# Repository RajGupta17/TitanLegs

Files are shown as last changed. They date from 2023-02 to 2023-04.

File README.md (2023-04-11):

## Description

TitanLegs is a 4 legged Quadruped robot which requires BLDC motors to actuate. And this is a 4 layered BLDC Servo Controller PCB which can operate upto 60V; 100A. This board has in-built micro-controller (ESP32), Gate Driver (DRV8323RS) that drives the BLDC Motor, High Voltage MOSFETs, Encoders (AS5047P), CAN BUS IC, 60V to 3.3V (2.5A) Buck Converter (TPS54260), USB to UART (CP2102) communication for programming ESP32 with Type-C, and few internal circuitry.

## 3D Model:

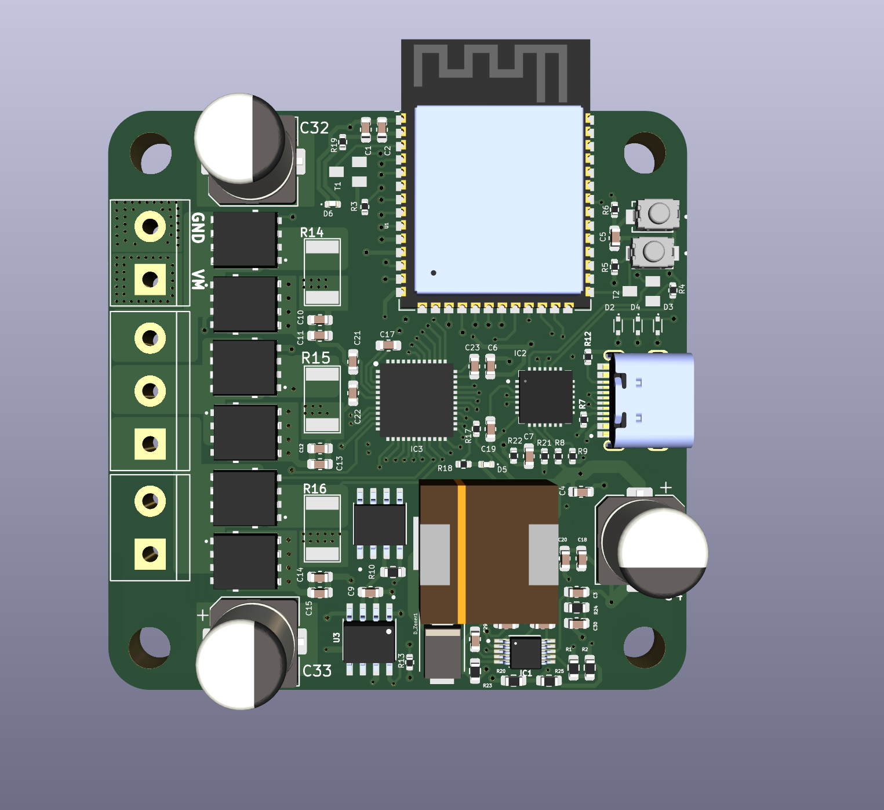
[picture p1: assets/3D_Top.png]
3D_Top


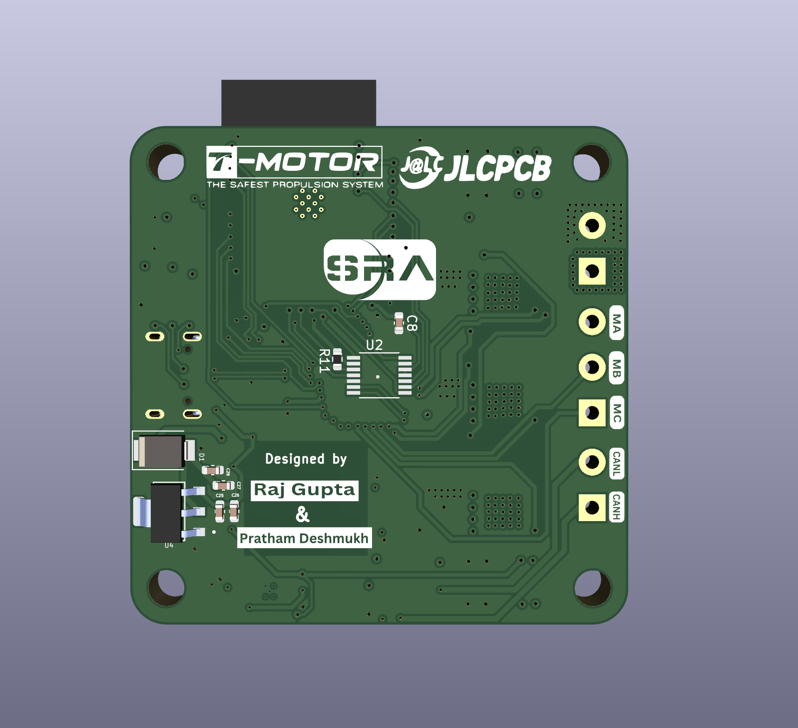
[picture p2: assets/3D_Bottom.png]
3D_Bottom


## Schematic Design:

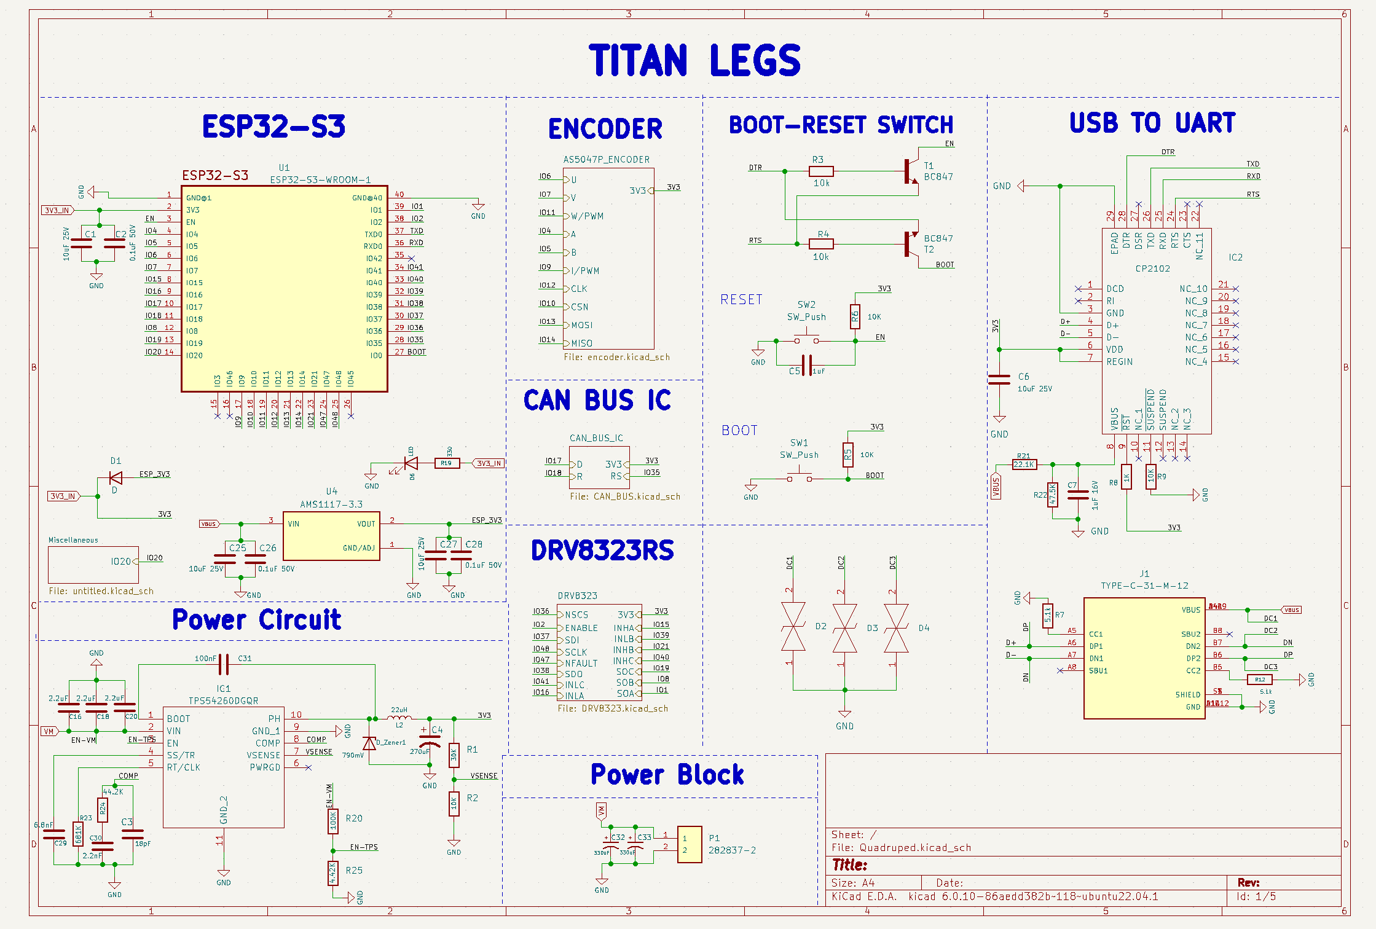
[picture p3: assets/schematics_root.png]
schematics_1


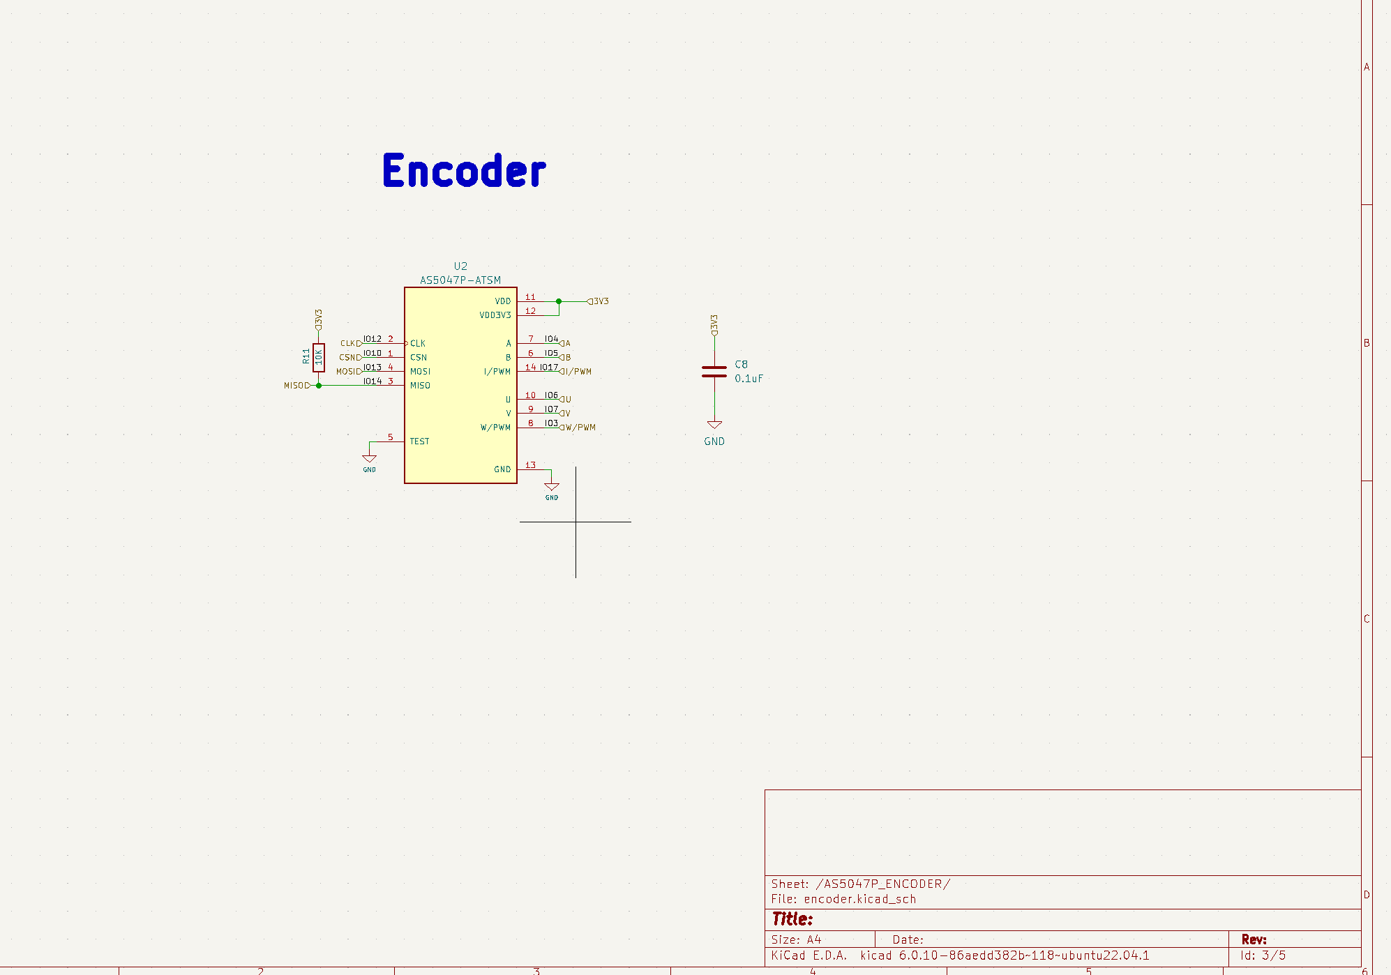
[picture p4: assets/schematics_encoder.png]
schematics encoder


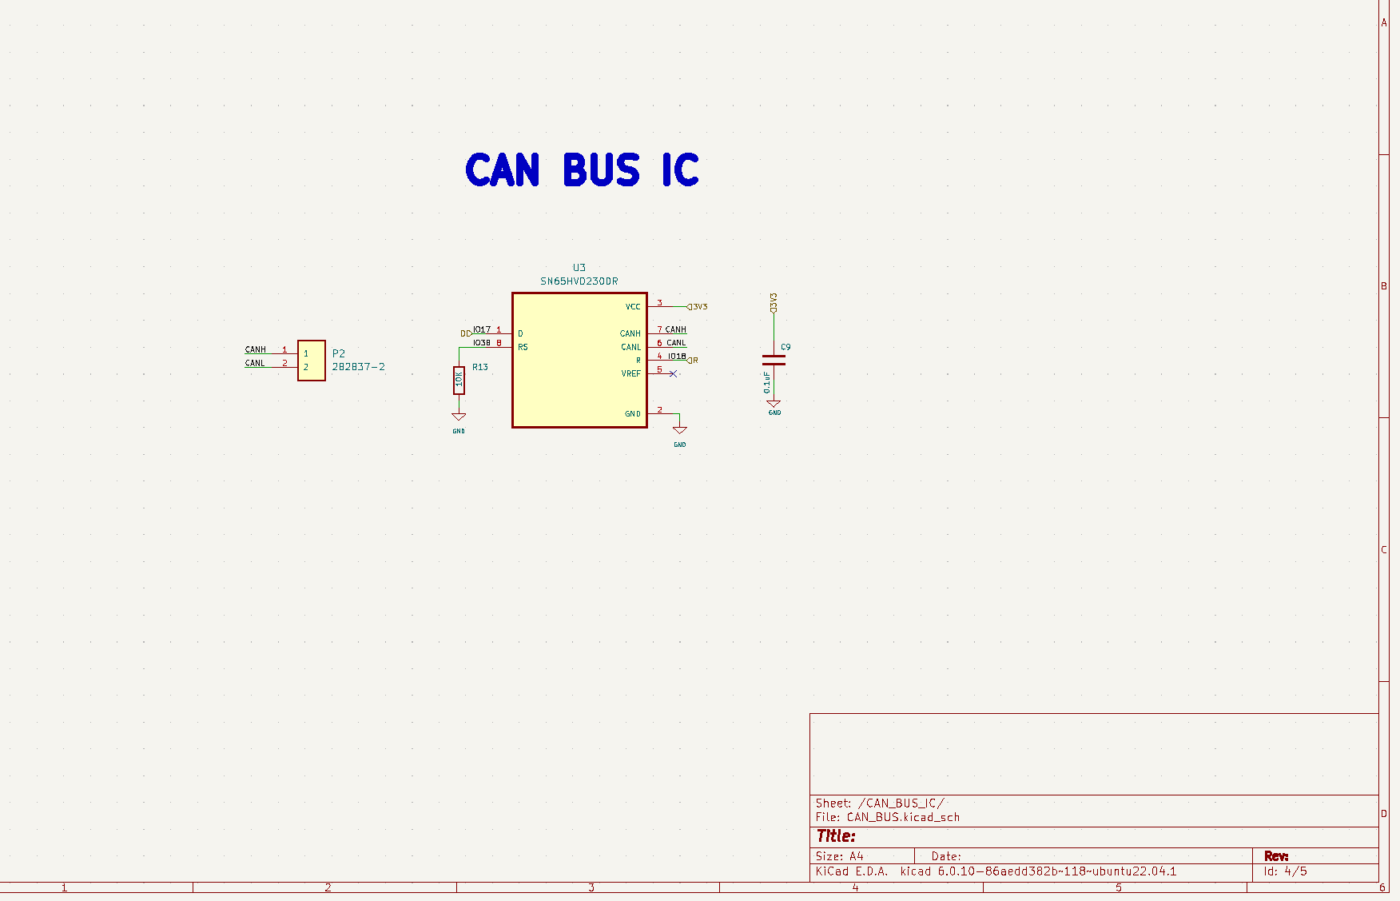
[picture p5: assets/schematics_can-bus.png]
schematics can bus


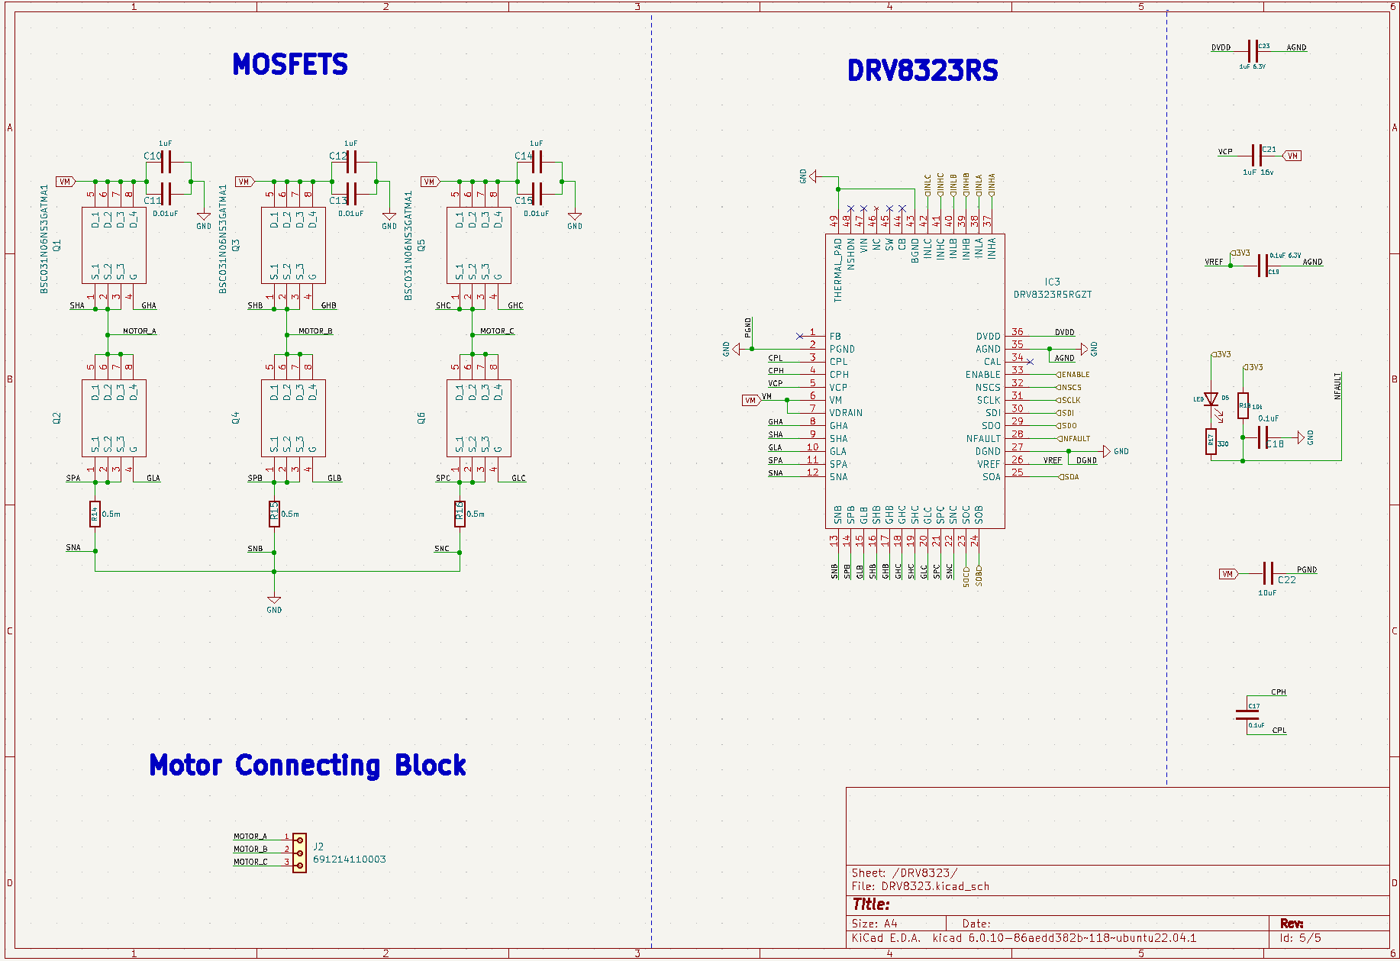
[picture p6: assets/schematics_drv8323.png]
schematics drv8323


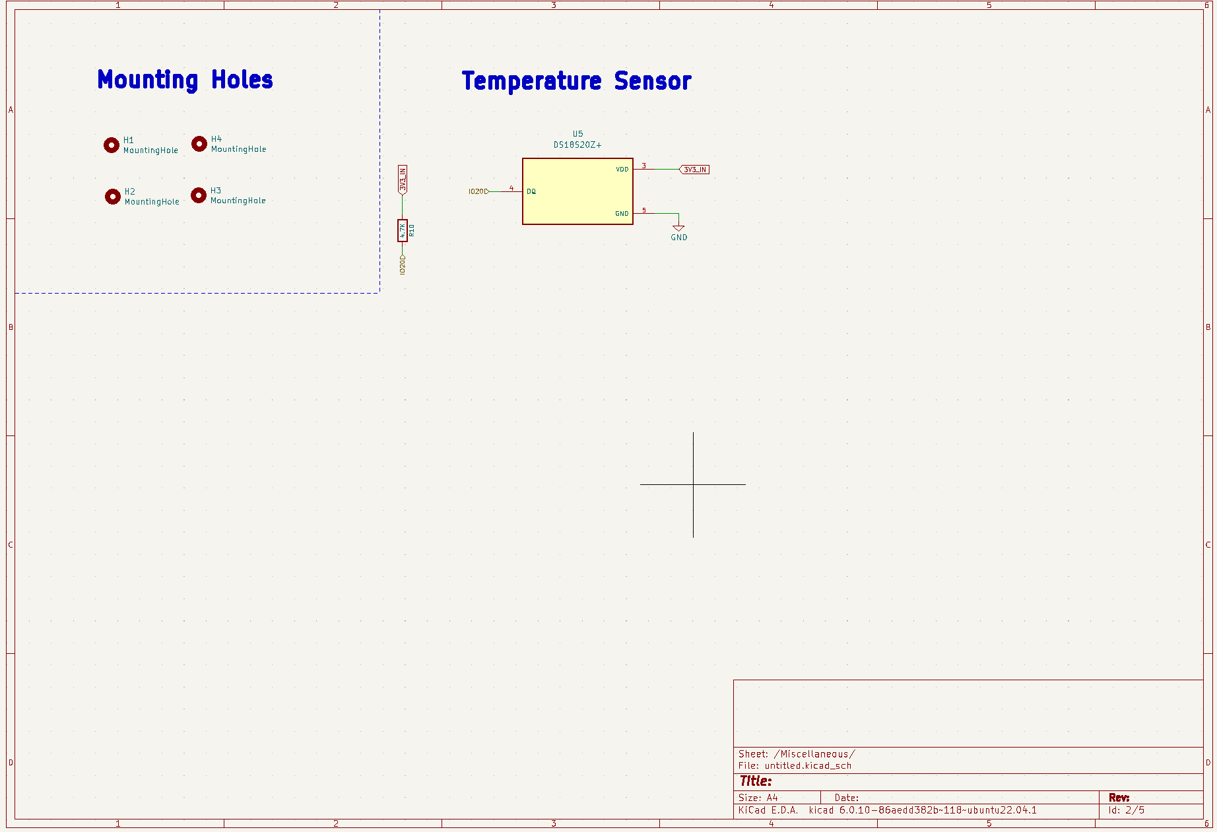
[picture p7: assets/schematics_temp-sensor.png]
schematics miscellenous


## PCB Layers:

### All Layers

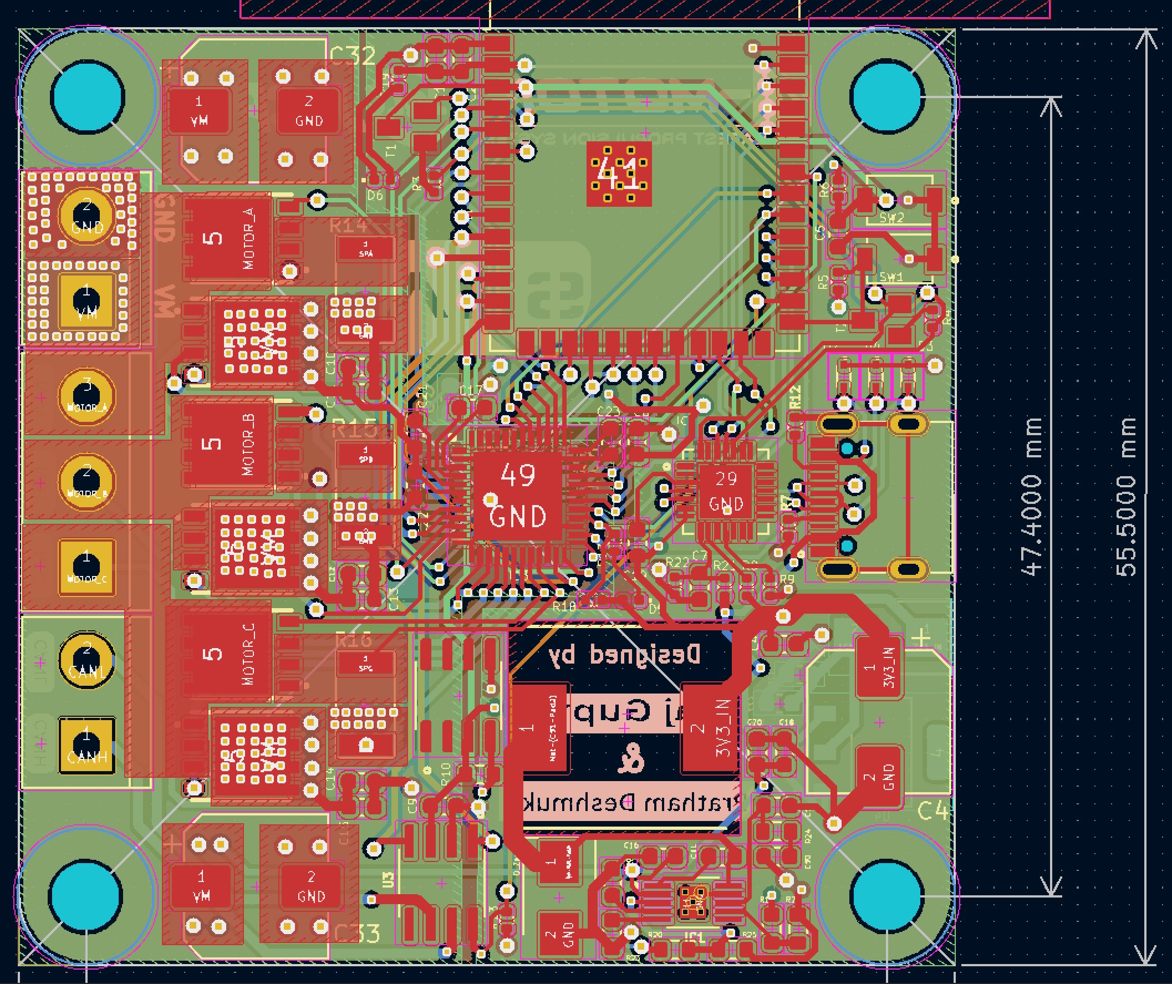
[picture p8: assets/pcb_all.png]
all layers


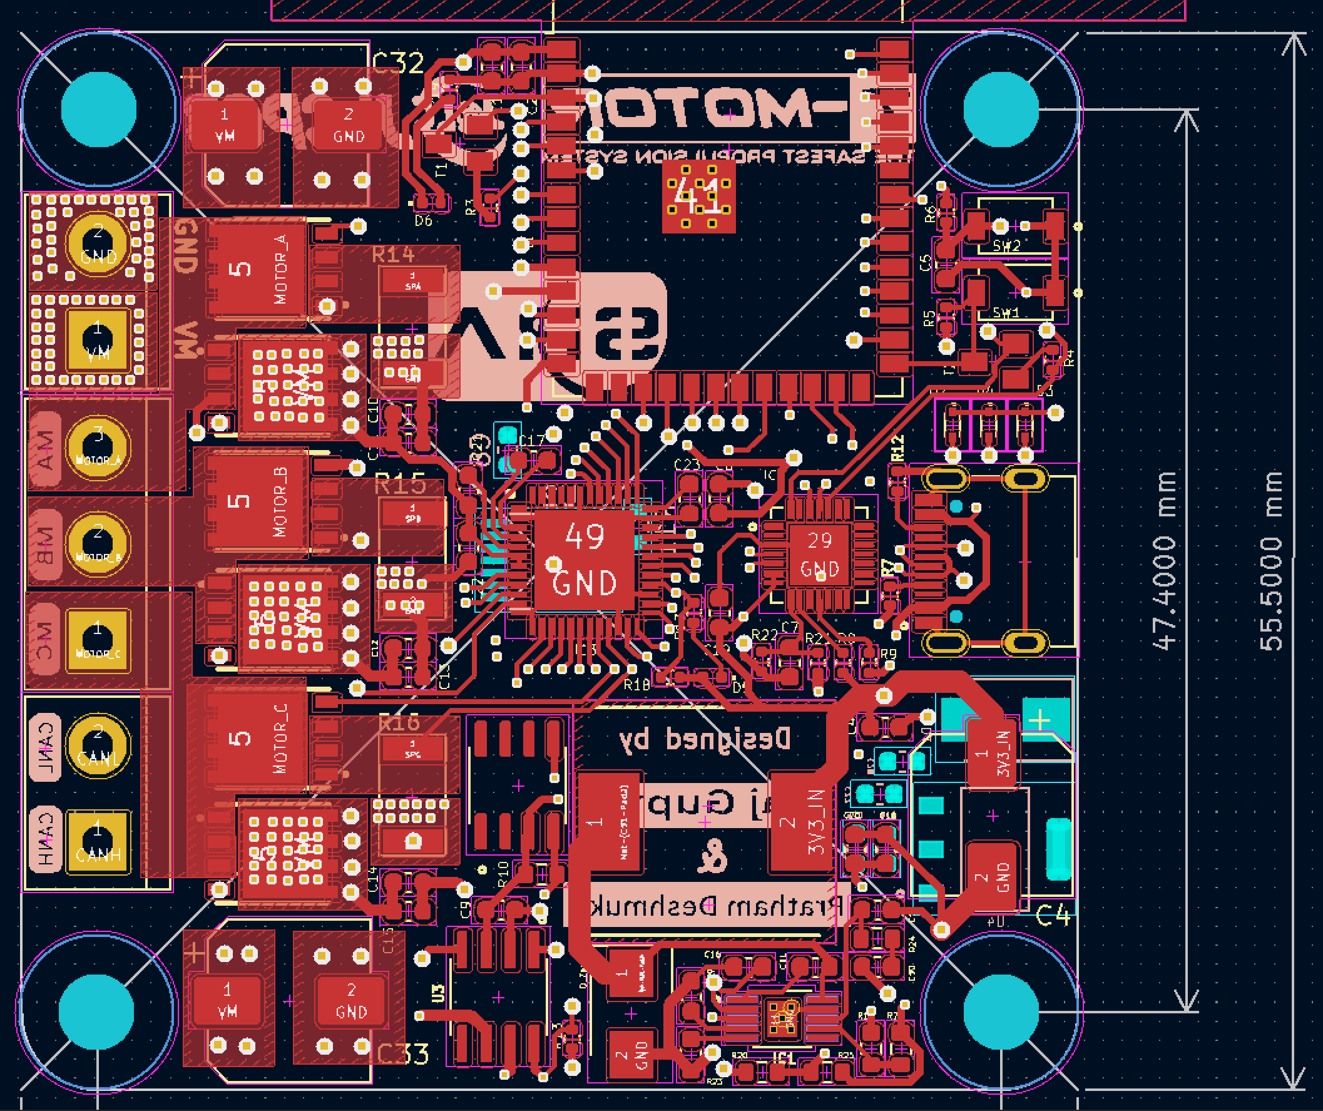
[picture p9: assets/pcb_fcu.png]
top layer


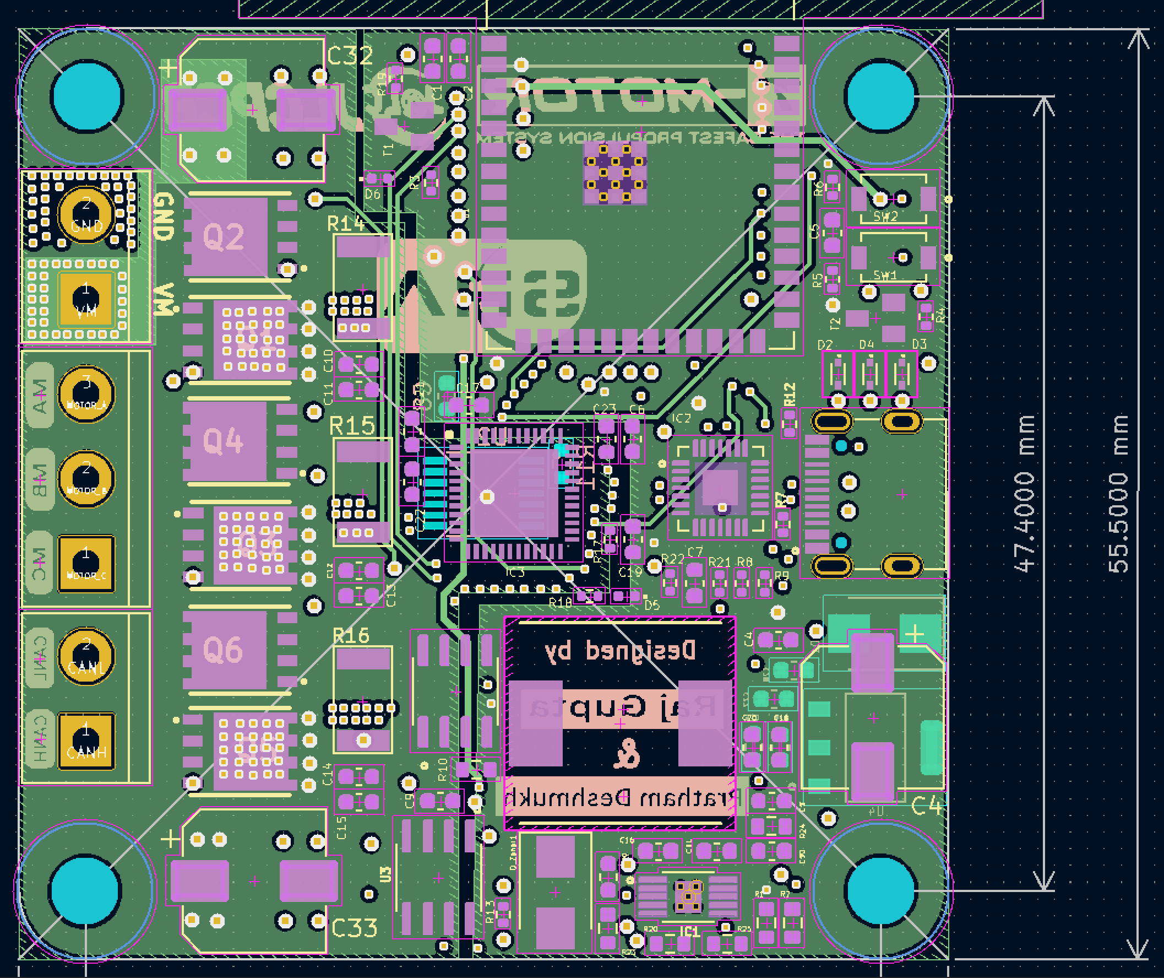
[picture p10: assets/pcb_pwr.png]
pwr layer


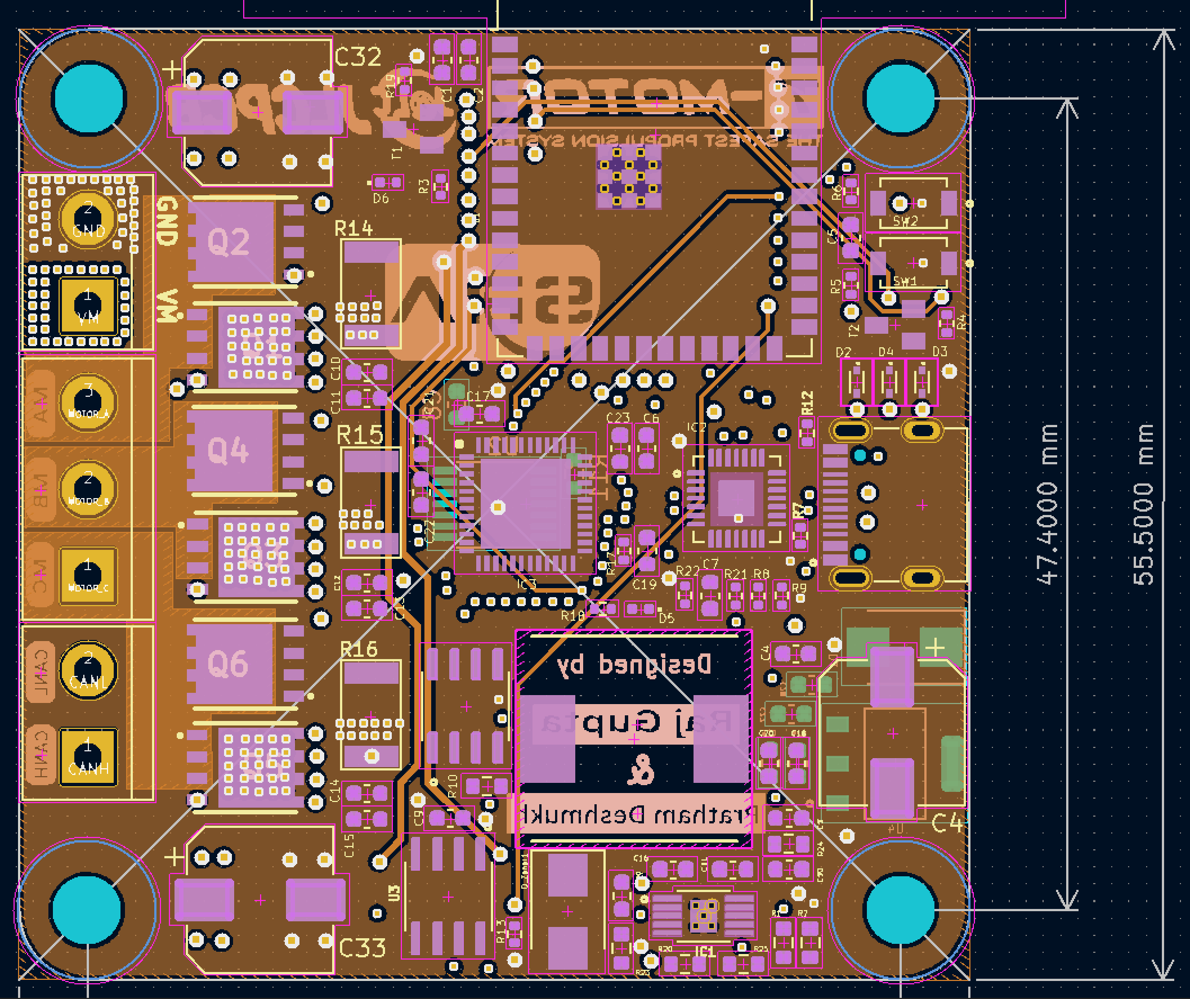
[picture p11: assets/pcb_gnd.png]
gnd layer


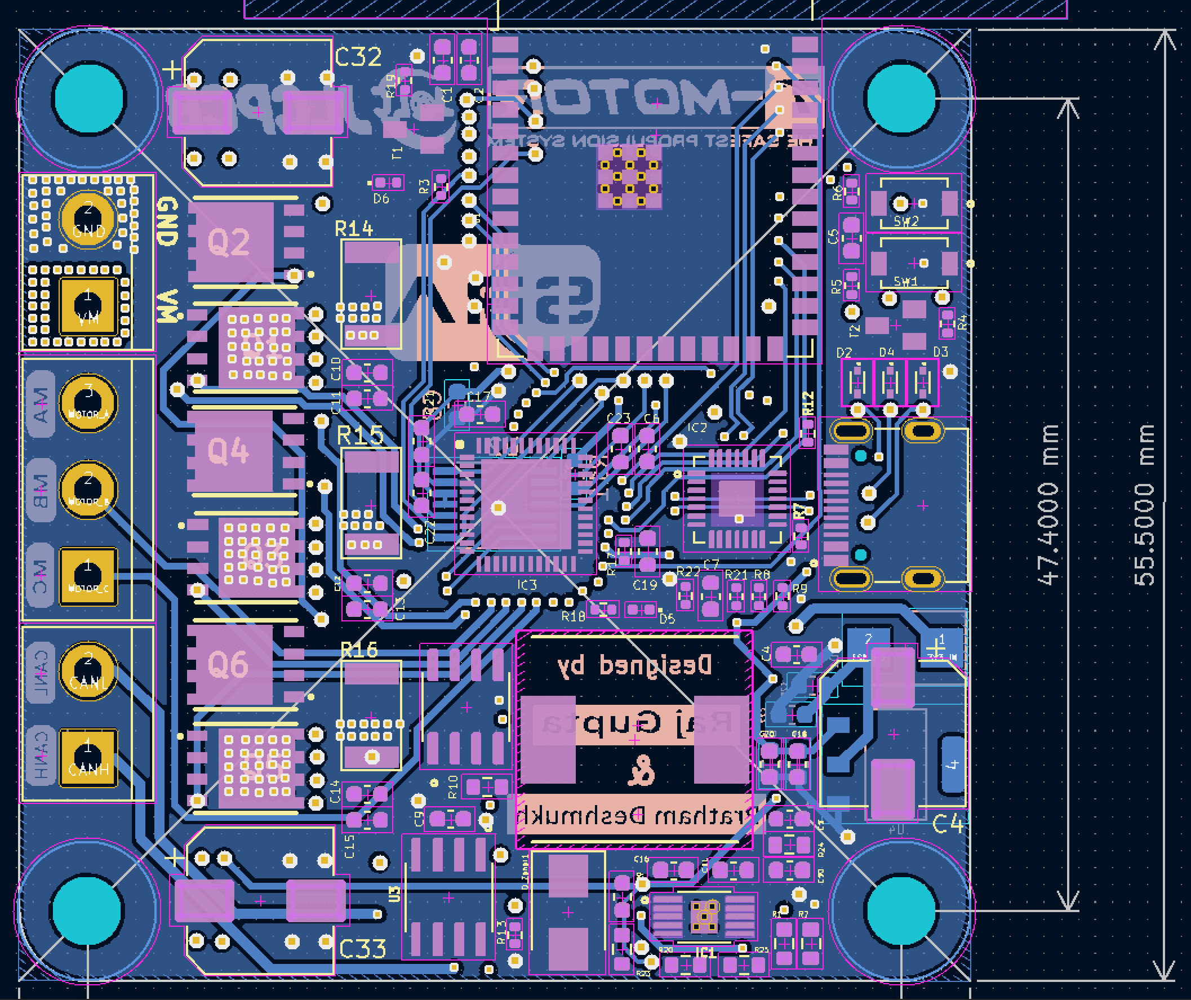
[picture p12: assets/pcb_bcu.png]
bottom layer


## Mentor

* [Chinmay Lonkar](https://github.com/ChinmayLonkar)

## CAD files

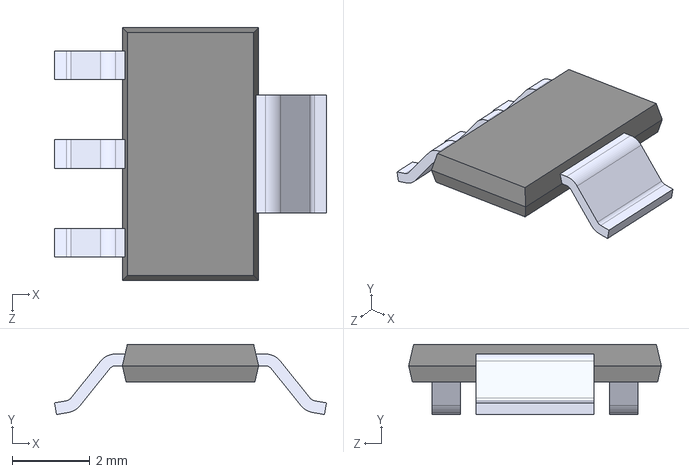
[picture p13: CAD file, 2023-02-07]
PCB_Design/component_libraries/AMS1117-3.3/AMS1117-3.3.step
7.00 x 1.80 x 6.50 mm

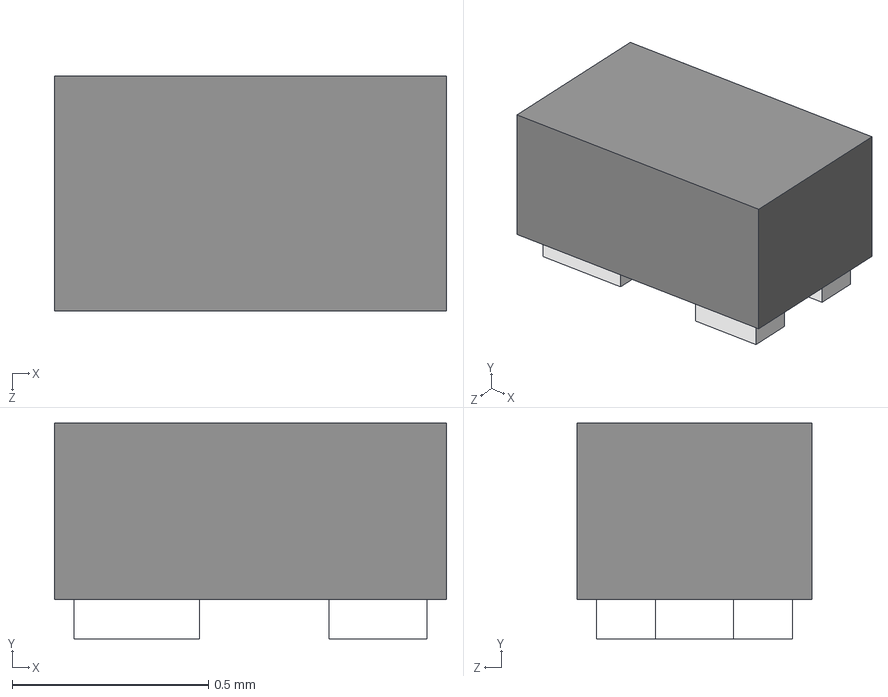
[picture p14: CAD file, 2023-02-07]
PCB_Design/component_libraries/BC847_BJT/BC847.step
1.00 x 0.55 x 0.6 mm

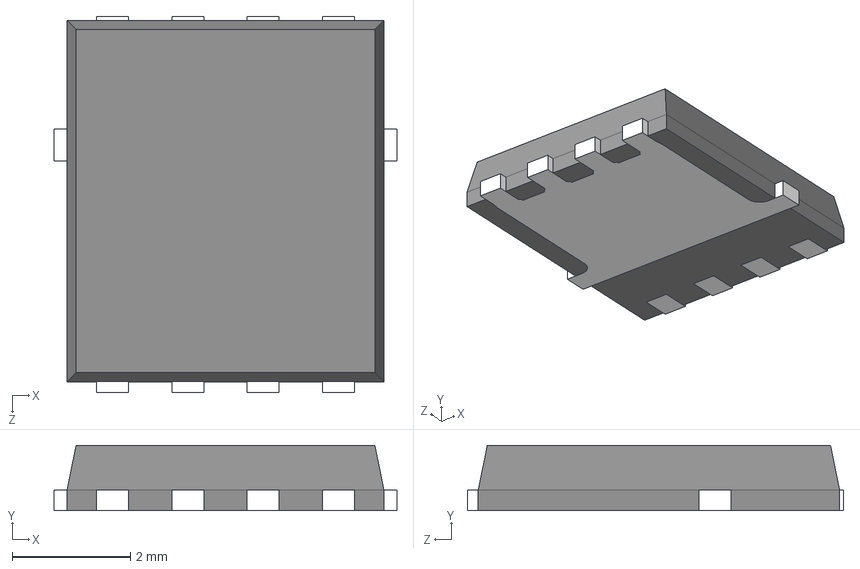
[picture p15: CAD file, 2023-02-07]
PCB_Design/component_libraries/BSC031N06NS3GATMA1_Mosfets/BSC031N06NS3GATMA1.stp
5.79 x 1.10 x 6.35 mm

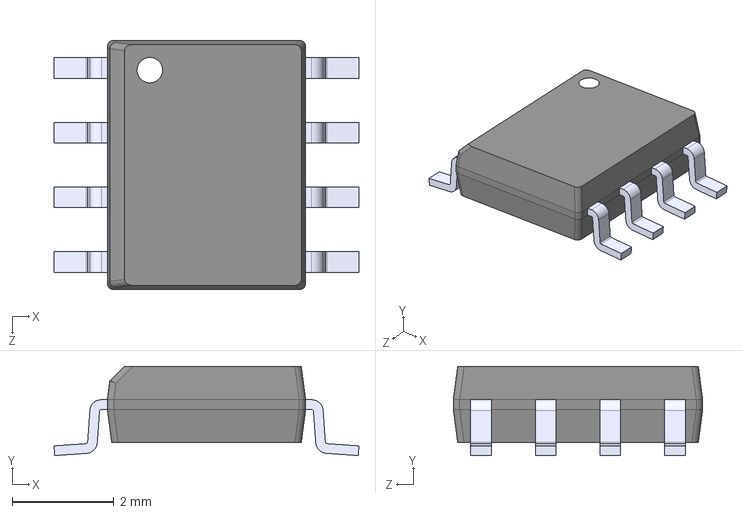
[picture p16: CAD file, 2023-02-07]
PCB_Design/component_libraries/CAN-BUS-IC/SN65HVD230DR.step
5.99 x 1.75 x 4.90 mm

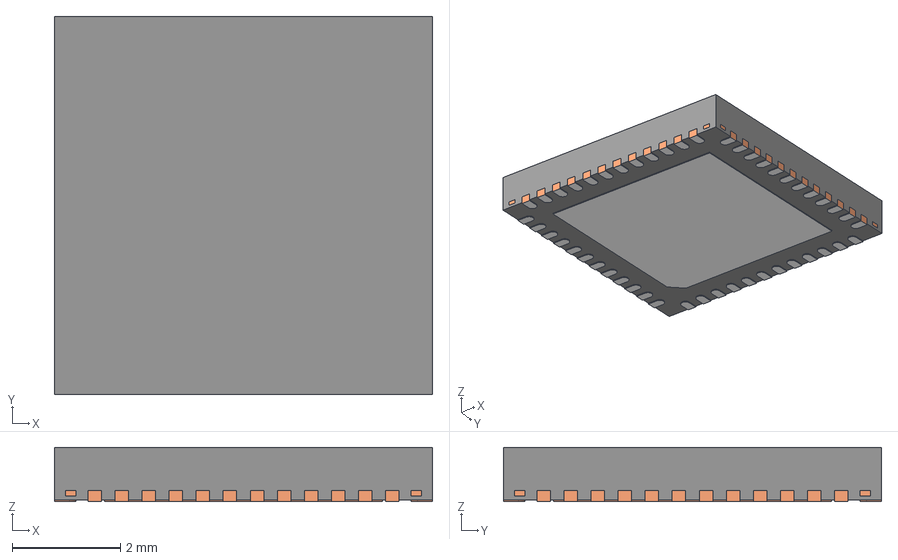
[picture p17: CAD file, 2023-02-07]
PCB_Design/component_libraries/DRV8323RS/DRV8323RSRGZT.stp
7.00 x 7.00 x 1.00 mm
BODY-QFN
FRAME-RGZ0048A
PIN1-ID

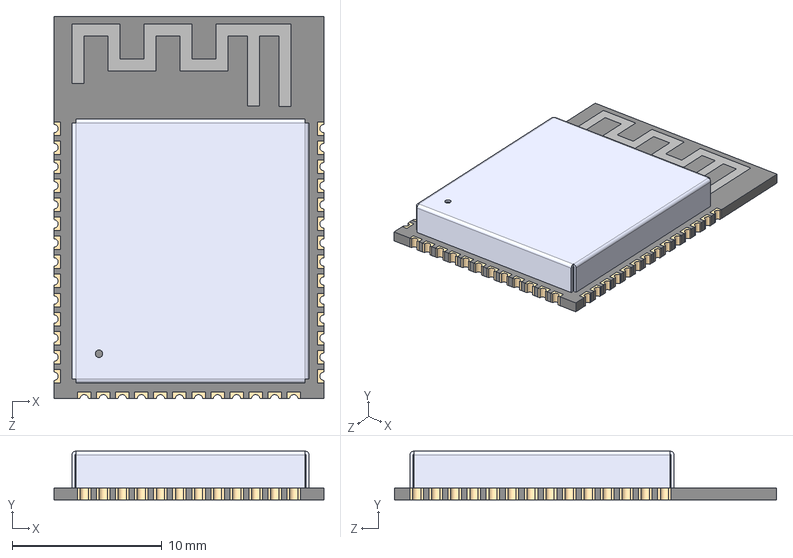
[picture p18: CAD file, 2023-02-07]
PCB_Design/component_libraries/ESP32-S3_NEW/ESP32-S3-WROOM-1.step
18.0 x 3.25 x 25.5 mm

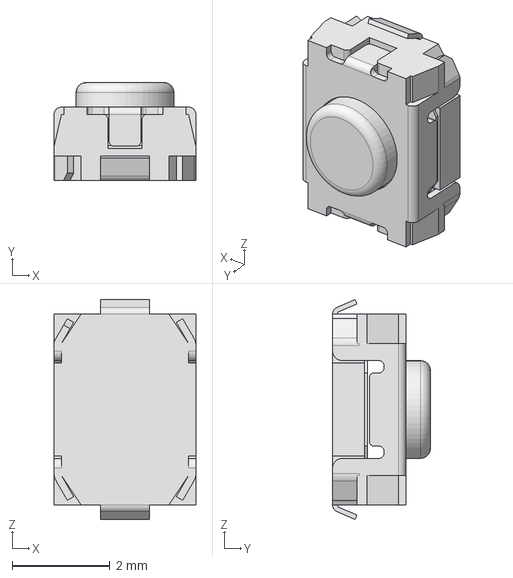
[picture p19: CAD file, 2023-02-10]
PCB_Design/component_libraries/SW_TL1015AF160QG/TL1015AF160QG.step
2.90 x 2.00 x 4.50 mm

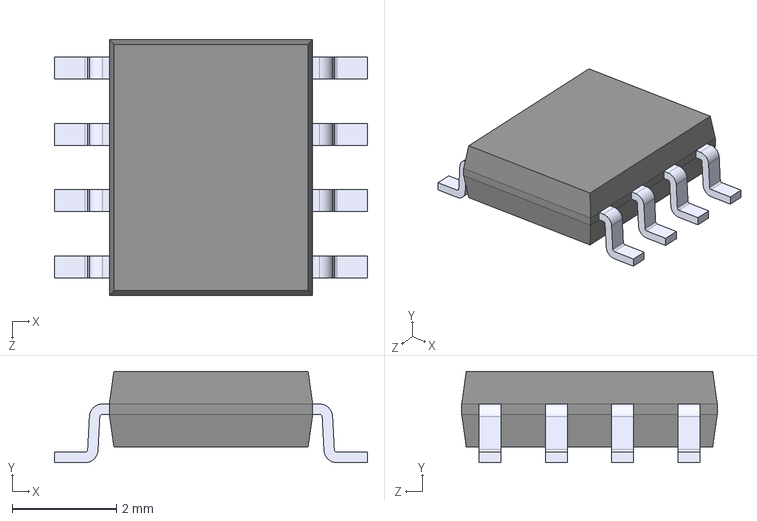
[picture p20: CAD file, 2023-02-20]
PCB_Design/component_libraries/Temp-Sensor_DS18S20Z_/DS18S20Z_.step
6.00 x 1.75 x 4.90 mm

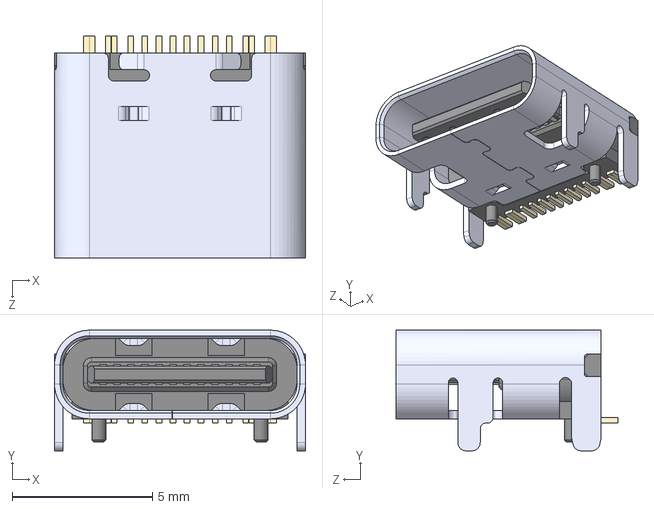
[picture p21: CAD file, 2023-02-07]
PCB_Design/component_libraries/usb c/TYPE-C-31-M-12.step
8.94 x 4.30 x 7.90 mm

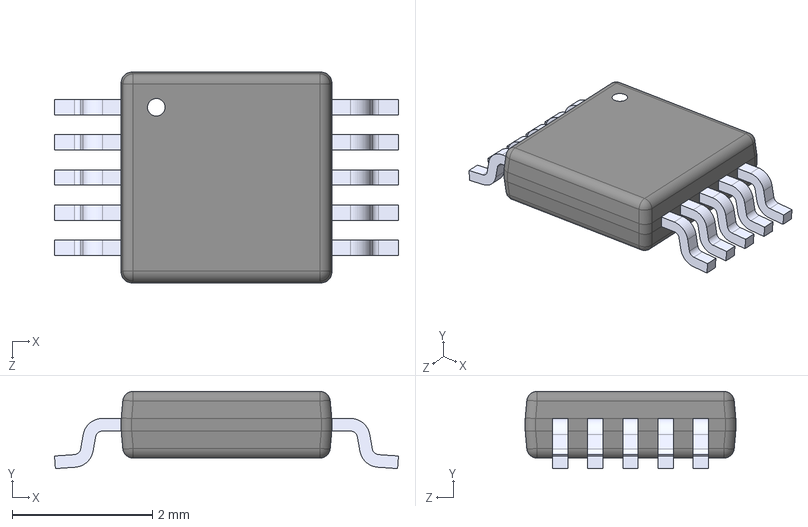
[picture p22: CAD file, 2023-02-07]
PCB_Design/component_libraries/Buck Converter/TPS54260DGQR.step
4.90 x 1.10 x 3.00 mm

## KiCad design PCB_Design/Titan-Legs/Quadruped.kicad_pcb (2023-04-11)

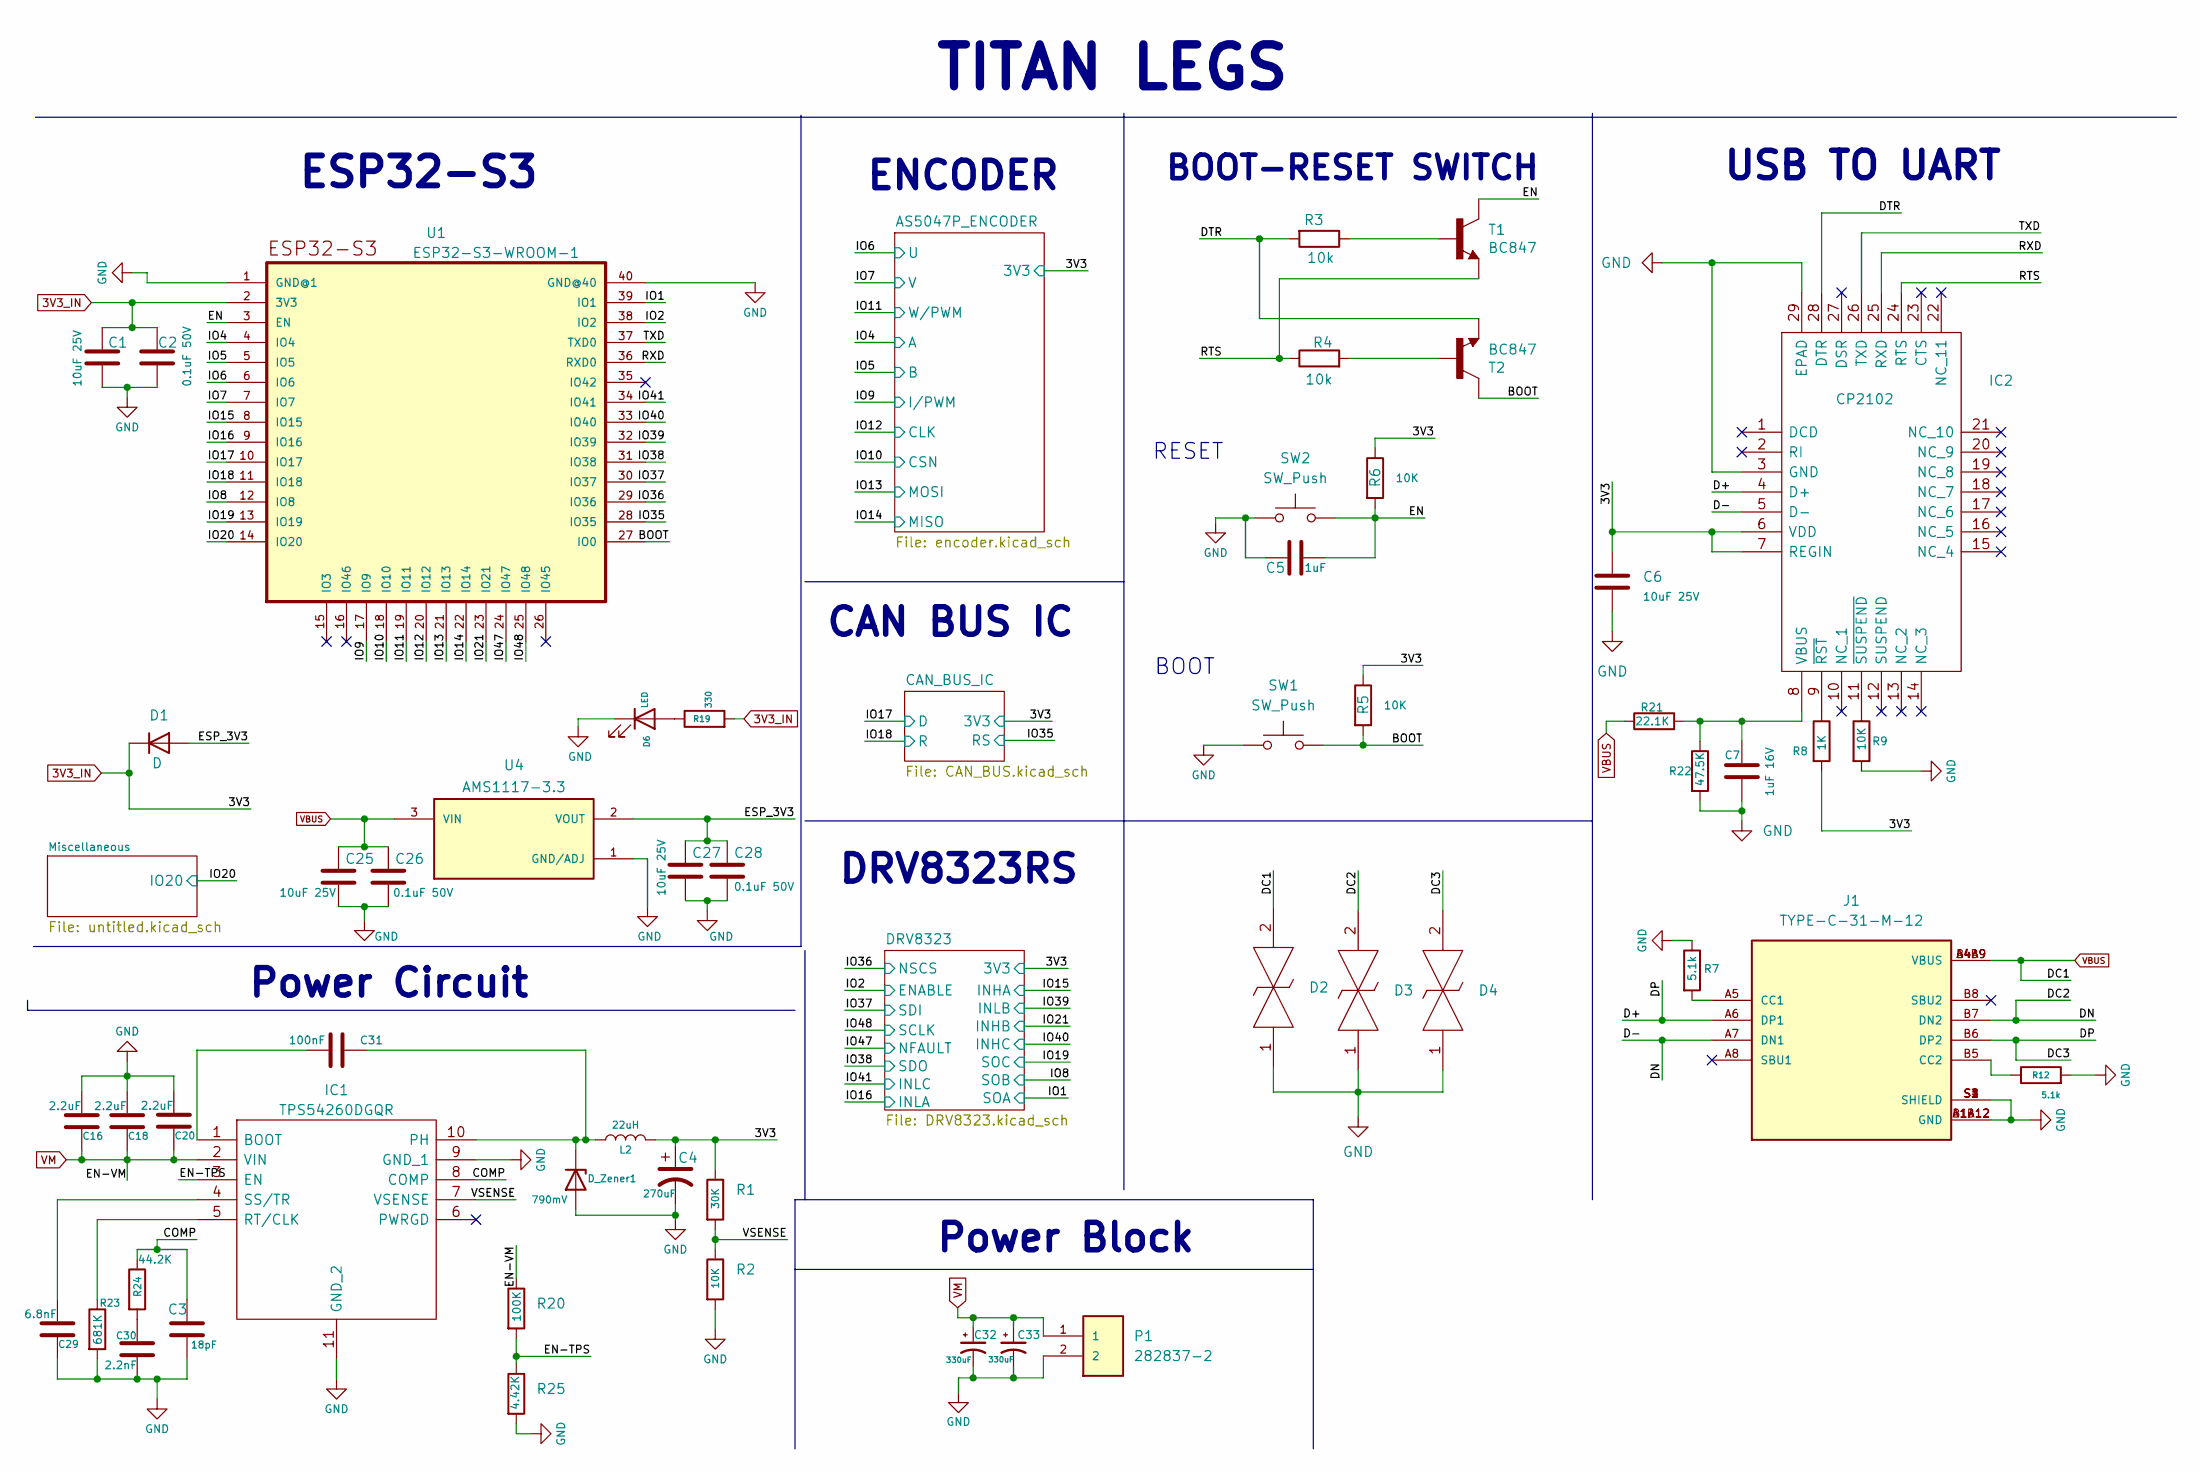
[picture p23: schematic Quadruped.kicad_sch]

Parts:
C1, C6, C25, C27: 10uF 25V; C_0603_1608Metric
C2, C26, C28: 0.1uF 50V; C_0603_1608Metric
C3: 18pF; C_0603_1608Metric
C4: 270uF; CP_Elec_8x10
C5: 1uF; C_0603_1608Metric
C7: 1uF 16V; C_0603_1608Metric
C16, C18, C20: 2.2uF; C_0603_1608Metric
C29: 6.8nF; C_0603_1608Metric
C30: 2.2nF; C_0603_1608Metric
C31: 100nF; C_0603_1608Metric
C32, C33: 330uF; CP_Elec_8x10
D1: D; D_SMB
D2, D3, D4: LESD5D5.0CT1G; LESD5D50CT1G; Manufacturer_Part_Number LESD5D5.0CT1G
D6: LED; LED_0402_1005Metric
D_Zener1: 790mV; D_SMB
IC1: TPS54260DGQR; IC_XTR111AIDGQR; Manufacturer_Part_Number TPS54260DGQR; Mouser Part Number 595-TPS54260DGQR
IC2: CP2102; QFN50P500X500X100-29N; Manufacturer_Part_Number CP2102; Mouser Part Number 634-CP2102
J1: TYPE-C-31-M-12; HRO_TYPE-C-31-M-12; PARTREV A
L2: 22uH; INDPM120120X800N
P1: 282837-2; TerminalBlock_bornier-2_P5.08mm
R1: 30K; R_0603_1608Metric
R2: 10K; R_0603_1608Metric
R3, R4: 10k; R_0402_1005Metric
R5, R6, R9: 10K; R_0402_1005Metric
R7, R12: 5.1k; R_0402_1005Metric
R8: 1K; R_0402_1005Metric
R19: 330; R_0402_1005Metric
R20: 100K; R_0603_1608Metric
R21: 22.1K; R_0402_1005Metric
R22: 47.5K; R_0402_1005Metric
R23: 681K; R_0603_1608Metric
R24: 44.2K; R_0603_1608Metric
R25: 4.42K; R_0603_1608Metric
SW1, SW2: SW_Push; SW_TL1015AF160QG
T1, T2: BC847; SOT23
U1: ESP32-S3-WROOM-1; MPN ESP32-S3-WROOM-1-N8R8
U4: AMS1117-3.3; SOT229P700X180-4N; PARTREV N/A

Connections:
3V3_IN: C1.1, C2.1, C4.1, C6.1, D1.1 (K), IC2.6 (VDD), IC2.7 (REGIN), L2.2, R1.1, R5.1, R6.1, R8.2, R19.2, U1.2 (3V3); also elsewhere on the board
/BOOT: R5.2, SW1.2, T2.3, U1.27 (IO0)
/COMP: C3.1, IC1.8 (COMP), R24.1
/D+: D4.2, IC2.4 (D+), J1.A6 (DP1), J1.B6 (DP2)
/D-: D3.2, IC2.5 (D-), J1.A7 (DN1), J1.B7 (DN2)
/DTR: IC2.28 (DTR), R3.2, T2.2
/EN: C5.2, R6.2, SW2.2, T1.3, U1.3 (EN)
/EN-TPS: IC1.3 (EN), R20.2, R25.1
/ESP_3V3: C27.1, C28.1, D1.2 (A), U4.2 (VOUT)
/IO1: U1.39 (IO1); also elsewhere on the board
/IO2: U1.38 (IO2); also elsewhere on the board
/IO4: U1.4 (IO4); also elsewhere on the board
/IO5: U1.5 (IO5); also elsewhere on the board
/IO6: U1.6 (IO6); also elsewhere on the board
/IO7: U1.7 (IO7); also elsewhere on the board
/IO8: U1.12 (IO8); also elsewhere on the board
/IO9: U1.17 (IO9); also elsewhere on the board
/IO10: U1.18 (IO10); also elsewhere on the board
/IO11: U1.19 (IO11); also elsewhere on the board
/IO12: U1.20 (IO12); also elsewhere on the board
/IO13: U1.21 (IO13); also elsewhere on the board
/IO14: U1.22 (IO14); also elsewhere on the board
/IO15: U1.8 (IO15); also elsewhere on the board
/IO16: U1.9 (IO16); also elsewhere on the board
/IO17: U1.10 (IO17); also elsewhere on the board
/IO18: U1.11 (IO18); also elsewhere on the board
/IO19: U1.13 (IO19); also elsewhere on the board
/IO20: U1.14 (IO20); also elsewhere on the board
/IO21: U1.23 (IO21); also elsewhere on the board
/IO35: U1.28 (IO35); also elsewhere on the board
/IO36: U1.29 (IO36); also elsewhere on the board
/IO37: U1.30 (IO37); also elsewhere on the board
/IO38: U1.31 (IO38); also elsewhere on the board
/IO39: U1.32 (IO39); also elsewhere on the board
/IO40: U1.33 (IO40); also elsewhere on the board
/IO41: U1.34 (IO41); also elsewhere on the board
/IO47: U1.24 (IO47); also elsewhere on the board
/IO48: U1.25 (IO48); also elsewhere on the board
/RTS: IC2.24 (RTS), R4.1, T1.2
/RXD: IC2.25 (RXD), U1.36 (RXD0)
/TXD: IC2.26 (TXD), U1.37 (TXD0)
/VSENSE: IC1.7 (VSENSE), R1.2, R2.1
GND: C1.2, C2.2, C3.2, C4.2, C5.1, C6.2, C7.2, C16.1, C18.1, C20.1, C25.2, C26.2, C27.2, C28.2, C29.2, C30.2, C32.2, C33.2, D2.1, D3.1, D4.1, D6.1 (K), D_Zener1.2 (A), IC1.9 (GND_1), IC1.11 (GND_2), IC1.13, IC1.14, IC2.3 (GND), IC2.29 (EPAD), J1.A1B12 (GND), J1.B1A12 (GND), J1.S1 (SHIELD), J1.S2 (SHIELD), J1.S3 (SHIELD), J1.S4 (SHIELD), P1.2, R2.2, R7.1, R9.2, R12.2, R22.2, R23.2, R25.2, SW1.1, SW2.1, U1.1 (GND@1), U1.40 (GND@40), U4.1 (GND/ADJ); also elsewhere on the board
unnamed: C7.1, IC2.8 (VBUS), R21.2, R22.1
unnamed: C29.1, IC1.4 (SS/TR)
unnamed: C30.1, R24.2
unnamed: C31.1, IC1.1 (BOOT)
unnamed: C31.2, D_Zener1.1 (K), IC1.10 (PH), L2.1
unnamed: D6.2 (A), R19.1
unnamed: IC1.5 (RT/CLK), R23.1
unnamed: IC2.9 (~RST), R8.1
unnamed: IC2.11 (~SUSPEND), R9.1
unnamed: J1.A5 (CC1), R7.2
unnamed: J1.B5 (CC2), R12.1
unnamed: R3.1, T1.1
unnamed: R4.2, T2.1
VBUS: C25.1, C26.1, D2.2, J1.A4B9 (VBUS), J1.B4A9 (VBUS), R21.1, U4.3 (VIN)
VM: C16.2, C18.2, C20.2, C32.1, C33.1, IC1.2 (VIN), P1.1, R20.1; also elsewhere on the board

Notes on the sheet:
ENCODER
CAN BUS IC
TITAN LEGS
BOOT
BOOT-RESET SWITCH
DRV8323RS
ESP32-S3
RESET
USB TO UART
Power Circuit
Power Block

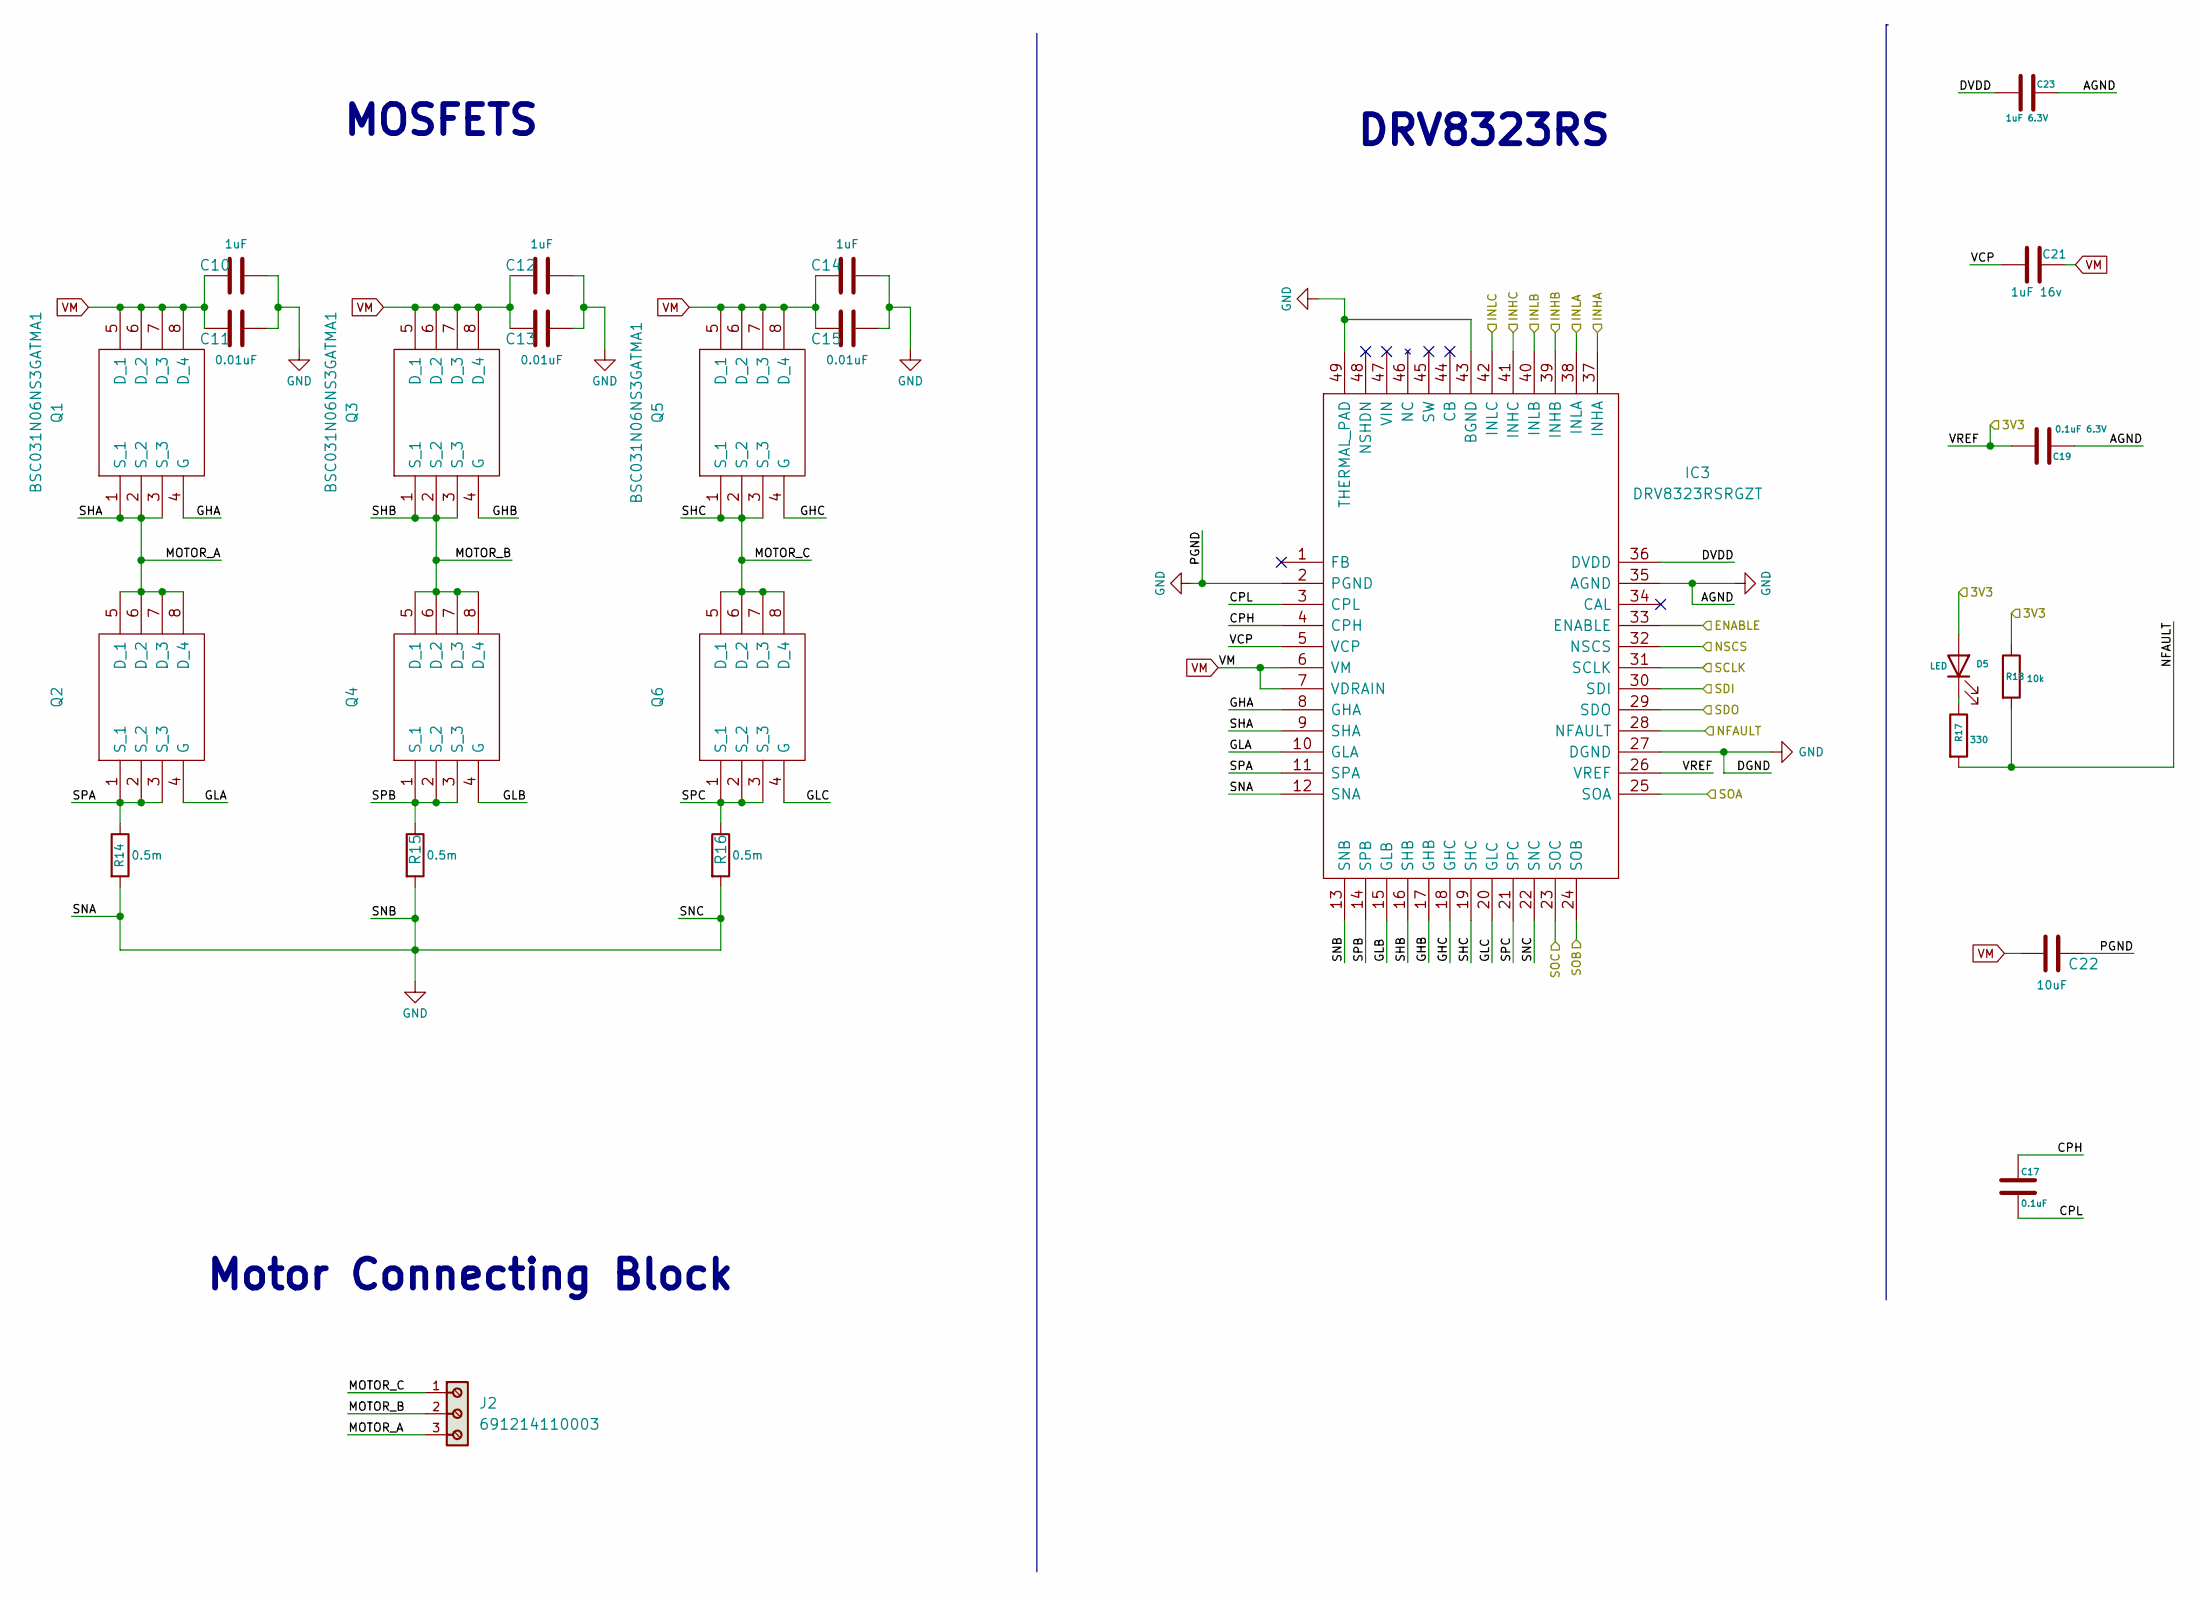
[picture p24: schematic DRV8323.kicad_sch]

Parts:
C10, C12, C14: 1uF; C_0603_1608Metric
C11, C13, C15: 0.01uF; C_0603_1608Metric
C17: 0.1uF; C_0603_1608Metric
C19: 0.1uF 6.3V; C_0603_1608Metric
C21: 1uF 16v; C_0603_1608Metric
C22: 10uF; C_0603_1608Metric
C23: 1uF 6.3V; C_0603_1608Metric
D5: LED; LED_0402_1005Metric
IC3: DRV8323RSRGZT; QFN50P700X700X100-49N-D; Manufacturer_Part_Number DRV8323RSRGZT; Mouser Part Number 595-DRV8323RSRGZT
J2: 691214110003; TerminalBlock_bornier-3_P5.08mm; PART-NUMBER 691214110003
Q1, Q2, Q3, Q4, Q5, Q6: BSC031N06NS3GATMA1; PG-TDSON-8_1; Manufacturer_Part_Number BSC031N06NS3GATMA1
R14, R15, R16: 0.5m; R_0.5m
R17: 330; R_0402_1005Metric
R18: 10k; R_0402_1005Metric

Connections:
3V3_IN: C19.1, D5.2 (A), IC3.26 (VREF), R18.1; also elsewhere on the board
/DRV8323/CPH: C17.2, IC3.4 (CPH)
/DRV8323/CPL: C17.1, IC3.3 (CPL)
/DRV8323/DVDD: C23.1, IC3.36 (DVDD)
/DRV8323/GHA: IC3.8 (GHA), Q1.4 (G)
/DRV8323/GHB: IC3.17 (GHB), Q3.4 (G)
/DRV8323/GHC: IC3.18 (GHC), Q5.4 (G)
/DRV8323/GLA: IC3.10 (GLA), Q2.4 (G)
/DRV8323/GLB: IC3.15 (GLB), Q4.4 (G)
/DRV8323/GLC: IC3.20 (GLC), Q6.4 (G)
/DRV8323/MOTOR_A: IC3.9 (SHA), J2.3, Q1.1 (S_1), Q1.2 (S_2), Q1.3 (S_3), Q2.5 (D_1), Q2.6 (D_2), Q2.7 (D_3), Q2.8 (D_4)
/DRV8323/MOTOR_B: IC3.16 (SHB), J2.2, Q3.1 (S_1), Q3.2 (S_2), Q3.3 (S_3), Q4.5 (D_1), Q4.6 (D_2), Q4.7 (D_3), Q4.8 (D_4)
/DRV8323/MOTOR_C: IC3.19 (SHC), J2.1, Q5.1 (S_1), Q5.2 (S_2), Q5.3 (S_3), Q6.5 (D_1), Q6.6 (D_2), Q6.7 (D_3), Q6.8 (D_4)
/DRV8323/SPA: IC3.11 (SPA), Q2.1 (S_1), Q2.2 (S_2), Q2.3 (S_3), R14.1
/DRV8323/SPB: IC3.14 (SPB), Q4.1 (S_1), Q4.2 (S_2), Q4.3 (S_3), R15.1
/DRV8323/SPC: IC3.21 (SPC), Q6.1 (S_1), Q6.2 (S_2), Q6.3 (S_3), R16.1
/DRV8323/VCP: C21.1, IC3.5 (VCP)
/IO1: IC3.25 (SOA); also elsewhere on the board
/IO2: IC3.33 (ENABLE); also elsewhere on the board
/IO8: IC3.24 (SOB); also elsewhere on the board
/IO15: IC3.37 (INHA); also elsewhere on the board
/IO16: IC3.38 (INLA); also elsewhere on the board
/IO19: IC3.23 (SOC); also elsewhere on the board
/IO21: IC3.39 (INHB); also elsewhere on the board
/IO36: IC3.32 (NSCS); also elsewhere on the board
/IO37: IC3.30 (SDI); also elsewhere on the board
/IO38: IC3.29 (SDO); also elsewhere on the board
/IO39: IC3.40 (INLB); also elsewhere on the board
/IO40: IC3.41 (INHC); also elsewhere on the board
/IO41: IC3.42 (INLC); also elsewhere on the board
/IO47: IC3.28 (NFAULT), R17.2, R18.2; also elsewhere on the board
/IO48: IC3.31 (SCLK); also elsewhere on the board
GND: C10.2, C11.2, C12.2, C13.2, C14.2, C15.2, C19.2, C22.2, C23.2, IC3.2 (PGND), IC3.12 (SNA), IC3.13 (SNB), IC3.22 (SNC), IC3.27 (DGND), IC3.35 (AGND), IC3.43 (BGND), IC3.49 (THERMAL_PAD), R14.2, R15.2, R16.2; also elsewhere on the board
unnamed: D5.1 (K), R17.1
VM: C10.1, C11.1, C12.1, C13.1, C14.1, C15.1, C21.2, C22.1, IC3.6 (VM), IC3.7 (VDRAIN), Q1.5 (D_1), Q1.6 (D_2), Q1.7 (D_3), Q1.8 (D_4), Q3.5 (D_1), Q3.6 (D_2), Q3.7 (D_3), Q3.8 (D_4), Q5.5 (D_1), Q5.6 (D_2), Q5.7 (D_3), Q5.8 (D_4); also elsewhere on the board

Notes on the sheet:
DRV8323RS
MOSFETS
Motor Connecting Block

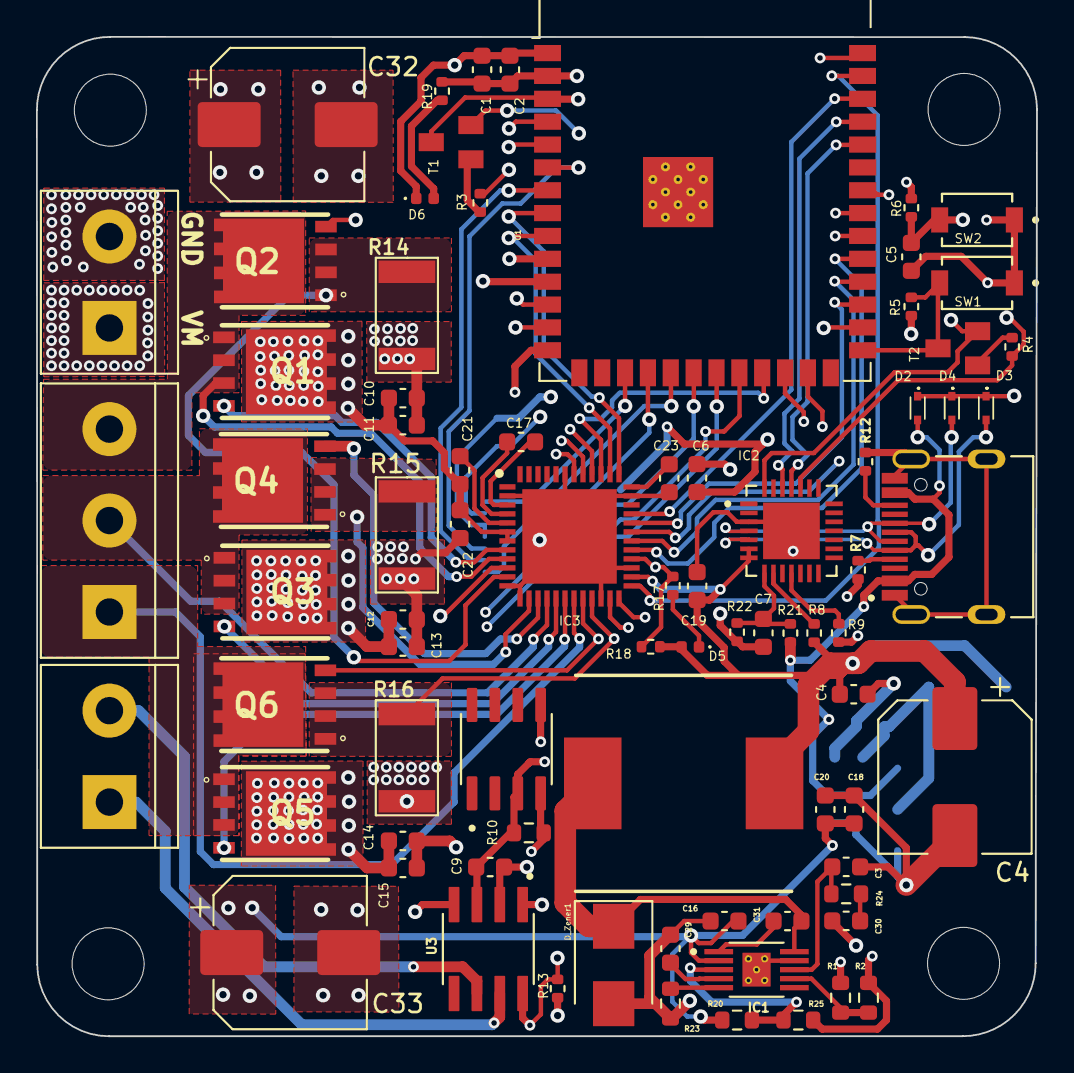
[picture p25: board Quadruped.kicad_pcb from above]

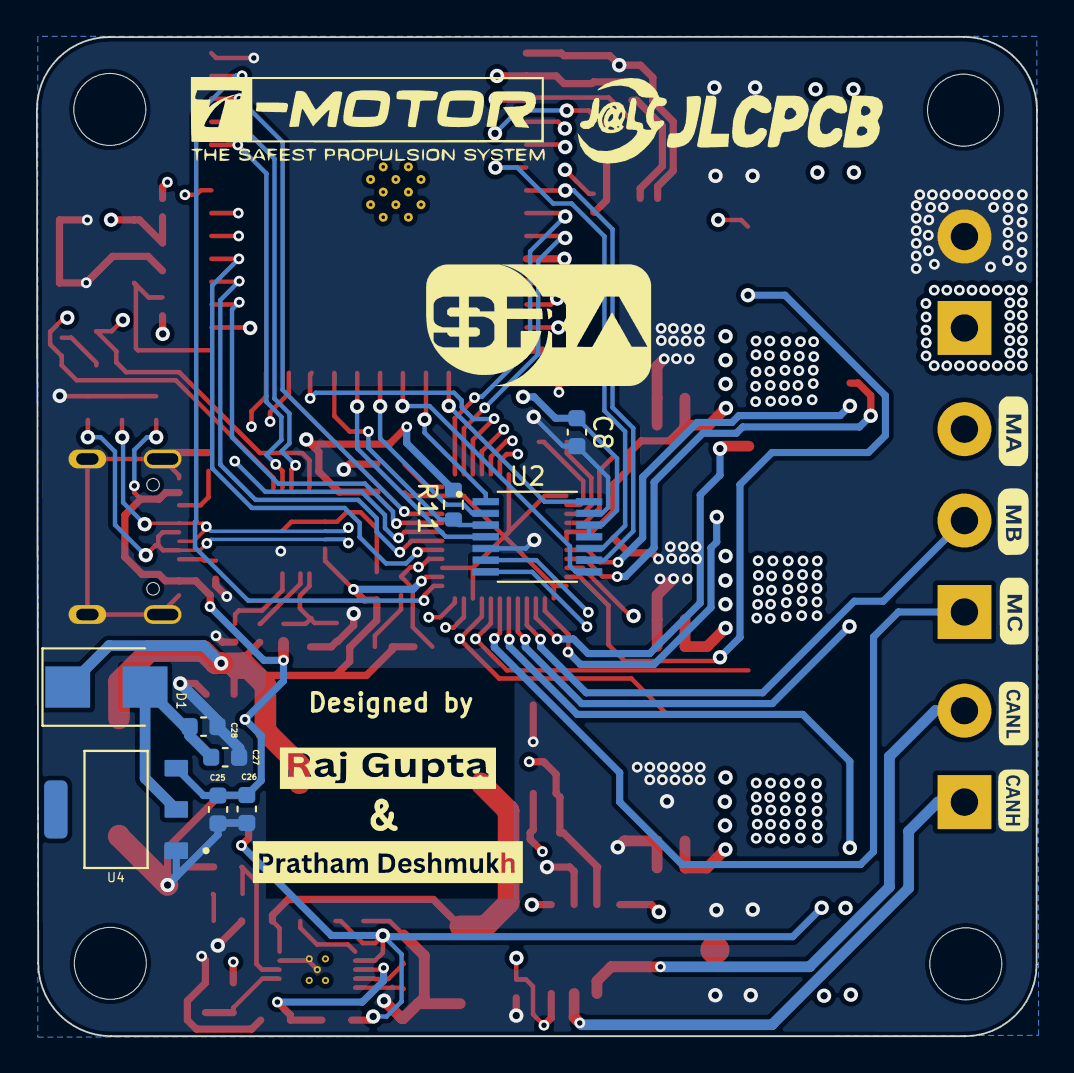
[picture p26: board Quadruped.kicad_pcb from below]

Board: 4 copper layers, 55.6 x 55.5 mm, 92 parts (9 on the bottom side), 77 nets.

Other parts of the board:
C4#2: 560uF; C_0603_1608Metric
C8, C9: 0.1uF; C_0603_1608Metric
H1, H2, H3, H4: MountingHole; MountingHole_4mm
P2: 282837-2; TerminalBlock_bornier-2_P5.08mm
R10: 4.7K; R_0603_1608Metric
R11: 10K; R_0603_1608Metric
R13: 10K; R_0402_1005Metric
U2: AS5047P-ATSM; SOP65P640X120-14N
U3: SN65HVD230DR; SOIC127P599X175-8N
U5: DS18S20Z+; DS18S20Z_

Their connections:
3V3_IN: C4#2.1, C8.1, C9.1, R10.1, R11.1, U2.11 (VDD), U2.12 (VDD3V3), U3.3 (VCC), U5.3 (VDD); also elsewhere on the board
/CAN_BUS_IC/CANH: P2.1, U3.7 (CANH)
/CAN_BUS_IC/CANL: P2.2, U3.6 (CANL)
/IO4: U2.7 (A); also elsewhere on the board
/IO5: U2.6 (B); also elsewhere on the board
/IO6: U2.10 (U); also elsewhere on the board
/IO7: U2.9 (V); also elsewhere on the board
/IO9: U2.14 (I/PWM); also elsewhere on the board
/IO10: U2.1 (CSN); also elsewhere on the board
/IO11: U2.8 (W/PWM); also elsewhere on the board
/IO12: U2.2 (CLK); also elsewhere on the board
/IO13: U2.4 (MOSI); also elsewhere on the board
/IO14: R11.2, U2.3 (MISO); also elsewhere on the board
/IO17: U3.1 (D); also elsewhere on the board
/IO18: U3.4 (R); also elsewhere on the board
/IO20: R10.2, U5.4 (DQ); also elsewhere on the board
/IO35: R13.1, U3.8 (RS); also elsewhere on the board
GND: C4#2.2, C8.2, C9.2, R13.2, U2.5 (TEST), U2.13 (GND), U3.2 (GND), U5.5 (GND); also elsewhere on the board

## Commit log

2023-02-07 schematics completed
    [1986660-3.step, 1_Lower_Limb_Connector.STL, 282837-2.step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]
2023-02-07 schematics 1st iteration completed
    [CAN_BUS.kicad_sch, DRV8323.kicad_sch, Quadruped.kicad_sch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]
2023-02-07 Schematics 2nd Iteration Completed
    [CAN_BUS.kicad_sch, DRV8323.kicad_sch, Quadruped.kicad_sch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]
2023-02-07 Added AMS1117 for ESP32-S3
    [AMS1117-3.3.step, CAN_BUS.kicad_sch, DRV8323.kicad_sch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]
2023-02-08 updated minor changes
    [CAN_BUS.kicad_sch, DRV8323.kicad_sch, Quadruped.kicad_sch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]
2023-02-09 added electrolytic capacitors
    [CAN_BUS.kicad_sch, DRV8323.kicad_sch, Quadruped.kicad_sch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]
2023-02-10 footprint assignment done
    [CAN_BUS.kicad_sch, CDRH127_LDNP-470MC.SchLib, CDRH127_LDNP-470MC.stp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]
2023-02-12 DRV8323 and CP2102 routing initiated
    [1546216-3.SchLib, 1546216-3.stp, 15462163.PcbLib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]
2023-02-20 updating recent changes
    [691214110003.step, CAN_BUS.kicad_sch, CDRH127_LDNP-470MC.step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]
2023-02-28 Copper filled VM to mosfets
    [Quadruped.kicad_pcb, Quadruped.kicad_sch, encoder.kicad_sch]
2023-03-01 gpio pins updated
    [Quadruped.kicad_pcb]
2023-03-02 Remove unnecessary files in component libraries
    [1546216-3.SchLib, 1546216-3.stp, 15462163.PcbLib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]
2023-03-03 Add new placement for Quadruped PCB
    [DRV8323.kicad_sch, Quadruped.kicad_pcb, Quadruped.kicad_sch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]
2023-03-04 Added high voltage copper fills
    [CAN_BUS.kicad_sch, DRV8323.kicad_sch, Quadruped.kicad_pcb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]
2023-03-04 Added Complete ESP32 net traces
    [Quadruped.kicad_pcb]
2023-03-05 Added DRV8323RS Traces and some minor changes
    [CAN_BUS.kicad_sch, Quadruped.kicad_pcb, Quadruped.kicad_sch]
2023-03-05 Completed PCB Routing
    [Quadruped.kicad_pcb]
2023-03-05 Added Changes after First Review
    [Quadruped.kicad_pcb]
2023-03-19 Merged silkscreen changes and completed final prototype
    [Quadruped.kicad_pcb]
2023-03-20 removed unnecessary files
    [BSC031N06NS3GATMA1.stp, DRV8323RSRGZT.stp, QFN28_5X5_SIL.step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]
2023-03-20 Merged the silkscreen MA,MB,MC and added vias in shunt resistors
    [DRV8323.kicad_sch, Quadruped.kicad_pcb, Quadruped.kicad_sch]
2023-03-20 Merged the silkscreen MA,MB,MC and added more vias in shunt resistors
    [Quadruped.kicad_pcb, Quadruped.kicad_sch]
2023-03-20 Added JLCPCB Logo on Back Silkscreen and final Changes Merged
    [Quadruped.kicad_pcb]
2023-04-04 Added Electrolytic Capacitor for TPS54260 and resisotrs for EN pin
    [Quadruped.kicad_pcb, Quadruped.kicad_sch]
2023-04-05 Added Electrolytic Capacitor and moved AMS1117 to B.Cu
    [AMS1117-3.3.step, BC847.step, BSC031N06NS3GATMA1.stp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]
2023-04-11 Added updated readme along with assets
    [Quadruped.kicad_pcb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]
